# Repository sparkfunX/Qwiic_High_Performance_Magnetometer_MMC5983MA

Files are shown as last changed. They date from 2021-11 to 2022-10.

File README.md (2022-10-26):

# SparkX MMC5983MA Magnetometer Breakout

<p align="center">
  <a href="https://github.com/sparkfunX/Qwiic_High_Performance_Magnetometer_MMC5983MA/issues" alt="Issues">
    </a>
  <a href="https://github.com/sparkfunX/Qwiic_High_Performance_Magnetometer_MMC5983MA/blob/main/LICENSE.md" alt="License">
    </a>
  <a href="https://twitter.com/intent/follow?screen_name=sparkfun">
    </a>
</p>

SparkX Triple Axis Magnetometer - MMC5983MA (Qwiic) (https://www.sparkfun.com/products/19034)

*[SparkX Triple Axis Magnetometer - MMC5983MA (Qwiic) (SPX-19034)](https://www.sparkfun.com/products/19034)*

The MMC5983MA is a highly sensitive triple axis magnetometer by MEMSIC.
It is capable of sensing down to 0.4mG enabling a heading accuracy of ±0.5°.
Output rates of 1000Hz, ±8G FSR, and 18-bit resolution make the MMC5983MA a phenomenal magnetic sensor for electronic compass applications.

### Important Note:

An updated version of this product is available:

SparkFun 9DoF IMU Breakout - ISM330DHCX, MMC5983MA (Qwiic) (https://www.sparkfun.com/products/19895)

*[SparkFun 9DoF IMU Breakout - ISM330DHCX, MMC5983MA (Qwiic) (SEN-19895)](https://www.sparkfun.com/products/19895)*

SparkFun Micro Magnetometer - MMC5983MA (Qwiic) (https://www.sparkfun.com/products/19921)

*[SparkFun Micro Magnetometer - MMC5983MA (Qwiic) (SEN-19921)](https://www.sparkfun.com/products/19921)*

## Repository Contents

* **[/Documents](/Documents/)** - MMC5983MA datasheet
* **[/Hardware](/Hardware/)** - Eagle design files (.brd, .sch)

## Product Versions

* [SPX-19034](https://www.sparkfun.com/products/19034) - Initial SparkX Release

## License Information

This product is _**open source**_! 

Please review the LICENSE.md file for license information. 

If you have any questions or concerns on licensing, please contact technical support on our [SparkFun forums](https://forum.sparkfun.com/viewforum.php?f=152).

Distributed as-is; no warranty is given.

- Your friends at SparkFun.

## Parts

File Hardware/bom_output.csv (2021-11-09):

Qty | PROD_ID | Names | Value | Package
1 | CAP-00810 | C1 | 0.1uF | 0603
1 | CAP-11015 | C2 | 10uF | 0603
1 | DIO-00819 | D1 | RED | LED-0603
2 | CONN-13694 | J1; J2 | Qwiic | JST04_1MM_RA
2 | RES-08272 | R1; R2 | 2.2k | 0603
1 | RES-07856 | R3 | 1k | 0603
1 | RES-00824 | R4 | 10k | 0603
1 | IC-16314 | U1 | MMC5893MA_QFN16 | LGA-16-3X3MM-4X4PINS

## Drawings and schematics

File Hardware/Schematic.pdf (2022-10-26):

3.3V

3.3V

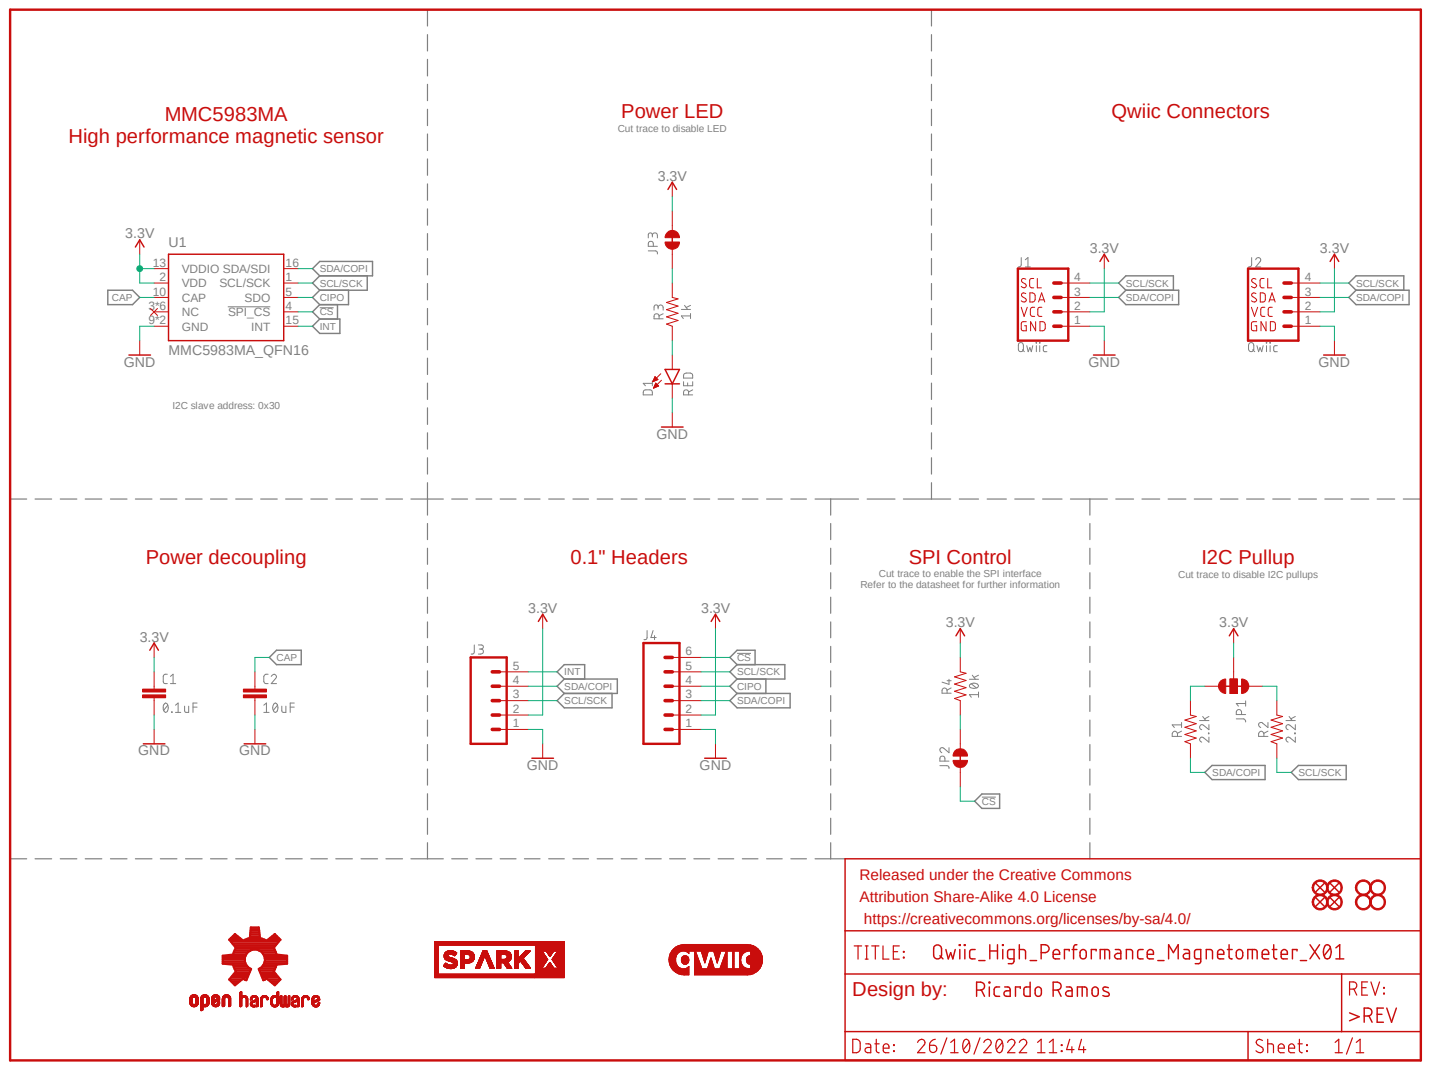
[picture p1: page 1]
I2C slave address: 0x30; Cut trace to enable the SPI interface; Cut trace to disable I2C pullups Refer to the datasheet for further information; GND; MMC5983MA_QFN16; GND 9*2; VDD 2; SCL/SCK; 1 SDA/SDI; 16 VDDIO 13; SDO; 5 CAP 10; SPI_CS; INT; 6 CAP; CAP; SDA/COPI; SDA/COPI SDA/COPI; CIPO; Qwiic Connectors; 0.1" Headers; Power LED; Power decoupling; MMC5983MA; SPI Control; I2C Pullup; Design by:

Cut trace to disable LED

High performance magnetic sensor

Released under the Creative Commons
Attribution Share-Alike 4.0 License
https://creativecommons.org/licenses/by-sa/4.0/

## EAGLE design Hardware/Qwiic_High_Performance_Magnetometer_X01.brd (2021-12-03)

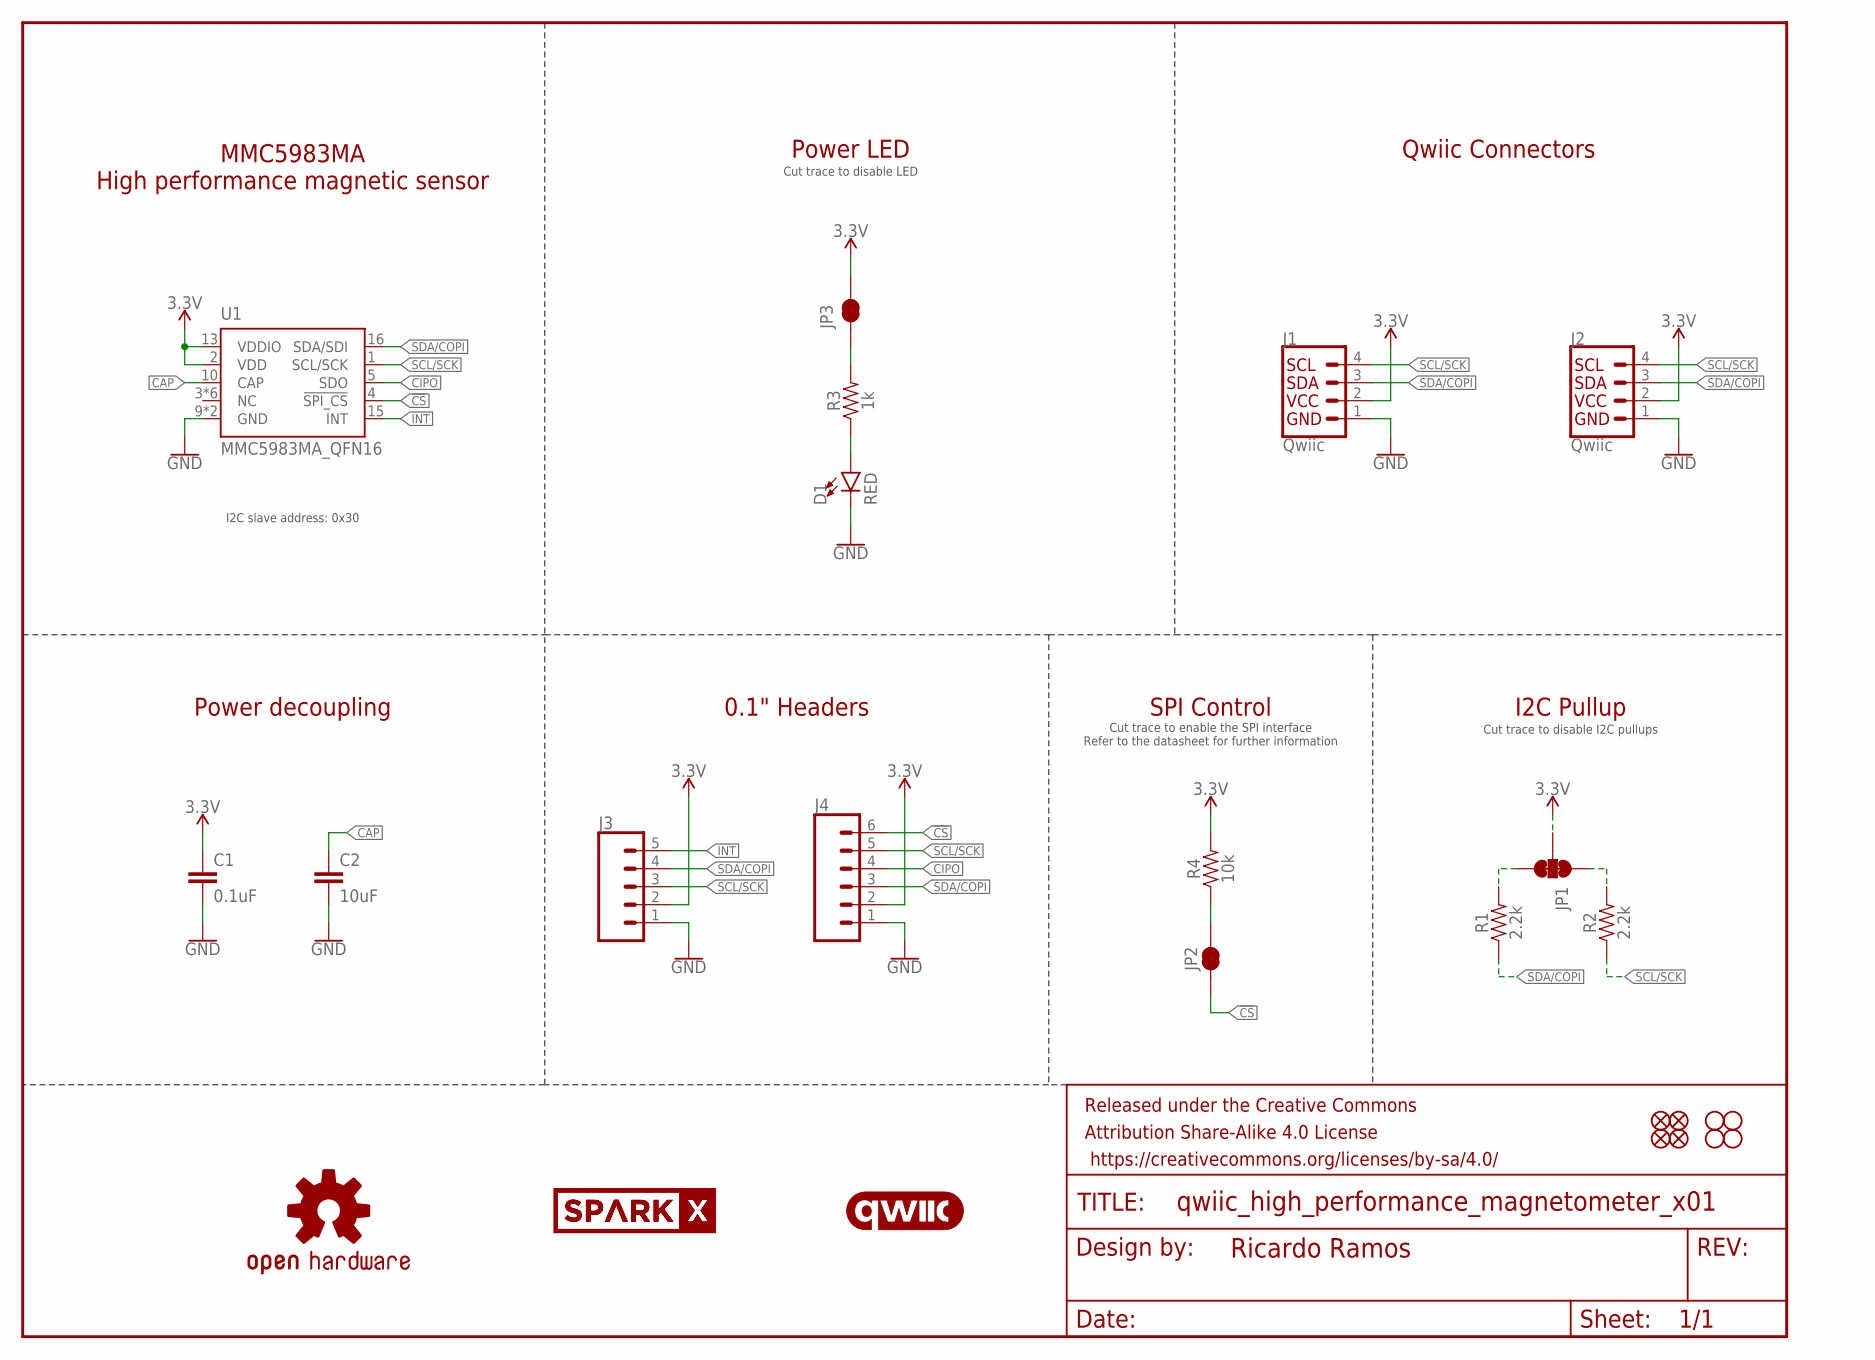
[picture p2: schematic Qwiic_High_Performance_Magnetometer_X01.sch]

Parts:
C1: 0.1uF; 0603
C2: 10uF; 0603
D1: RED; LED-0603
FD1, FD2, FD3, FD4: FIDUCIAL1X2; FIDUCIAL-1X2
FRAME1: FRAME-LETTERNO_PACKAGE; DUMMY
H1, H2, H3, H4: STAND-OFF
J1, J2: Qwiic; JST04_1MM_RA
J3: CONN_05NO_SILK; 1X05_NO_SILK
J4: CONN_06NO_SILK_NO_POP; 1X06_NO_SILK
JP1: JUMPER-SMT_3_2-NC_TRACE_SILK; SMT-JUMPER_3_2-NC_TRACE_SILK
JP2, JP3: JUMPER-SMT_2_NC_TRACE_SILK; SMT-JUMPER_2_NC_TRACE_SILK
LOGO1: OSHW-LOGOMINI; OSHW-LOGO-MINI
LOGO2: QWIIC_LOGO_5MM; QWIIC_5MM
R1, R2: 2.2k; 0603
R3: 1k; 0603
R4: 10k; 0603
U1: MMC5983MA_QFN16; LGA-16-3X3MM-4X4PINS
U$36: SPARKX-LOGO2; SPARKX-TINY
U$37: SPARKX-LOGO3; SPARKX-SMALL

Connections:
3.3V: C1.1, J1.2, J2.2, J3.2, J4.2, JP1.2, JP3.2, R4.2, U1.2 (VDD), U1.13 (VDDIO)
!CS!: J4.6, JP2.1, U1.4 (!SPI_CS!)
CAP: C2.1, U1.10 (CAP)
CIPO: J4.4, U1.5 (SDO)
GND: C1.2, C2.2, D1.C, J1.1, J2.1, J3.1, J4.1, U1.9 (GND), U1.11 (GND)
INT: J3.5, U1.15 (INT)
unnamed: JP3.1, R3.2
unnamed: JP1.1, R2.2
unnamed: JP1.3, R1.2
unnamed: D1.A, R3.1
unnamed: JP2.2, R4.1
SCL/SCK: J1.4, J2.4, J3.3, J4.5, R2.1, U1.1 (SCL/SCK)
SDA/COPI: J1.3, J2.3, J3.4, J4.3, R1.1, U1.16 (SDA/SDI)

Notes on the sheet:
Qwiic Connectors
Cut trace to disable LED
0.1" Headers
Power LED
Power decoupling
MMC5983MA High performance magnetic sensor
I2C slave address: 0x30
I2C Pullup
Cut trace to disable I2C pullups
SPI Control
Cut trace to enable the SPI interface Refer to the datasheet for further information

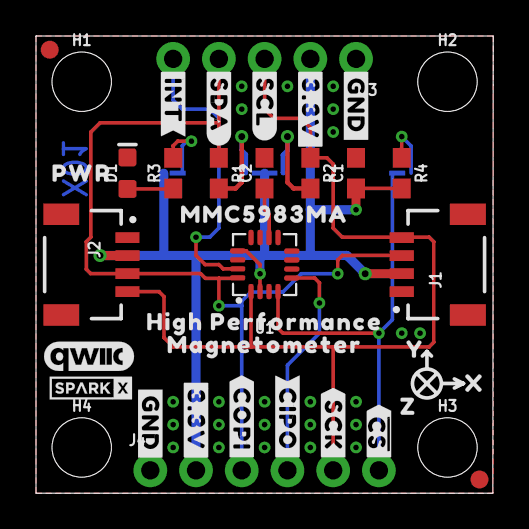
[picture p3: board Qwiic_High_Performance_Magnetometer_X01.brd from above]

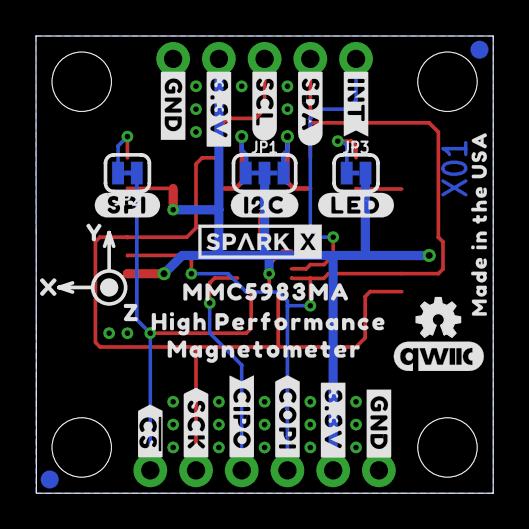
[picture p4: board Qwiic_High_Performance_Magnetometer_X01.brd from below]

Board: 2 copper layers, 25.4 x 25.4 mm, 68 parts (29 on the bottom side), 13 nets.

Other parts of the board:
LOGO3: QWIIC_LOGO_5MM; QWIIC_5MM
U$1, U$10: HIGH_PERFORMANCE11
U$2, U$35: #SCL#6
U$3, U$12, U$18, U$29: #3#3V#0
U$4, U$13, U$17, U$28: #GND#4
U$5, U$38: #SDA#5
U$6, U$31: #CIPO#11
U$7, U$16: #INT#7
U$8: PWR9
U$9, U$30: #COPI#12
U$11, U$24: MAGNETOMETER12
U$14, U$32: #SCK#13
U$15, U$33: ##CS##10
U$19, U$26: Y16
U$20, U$25: X15
U$21: #LED#8
U$22: #I2C#9
U$23: #SPI#9
U$27, U$39: Z17
U$34: MADE_IN_THE_USA20
U$41, U$42: MMC5983MA0

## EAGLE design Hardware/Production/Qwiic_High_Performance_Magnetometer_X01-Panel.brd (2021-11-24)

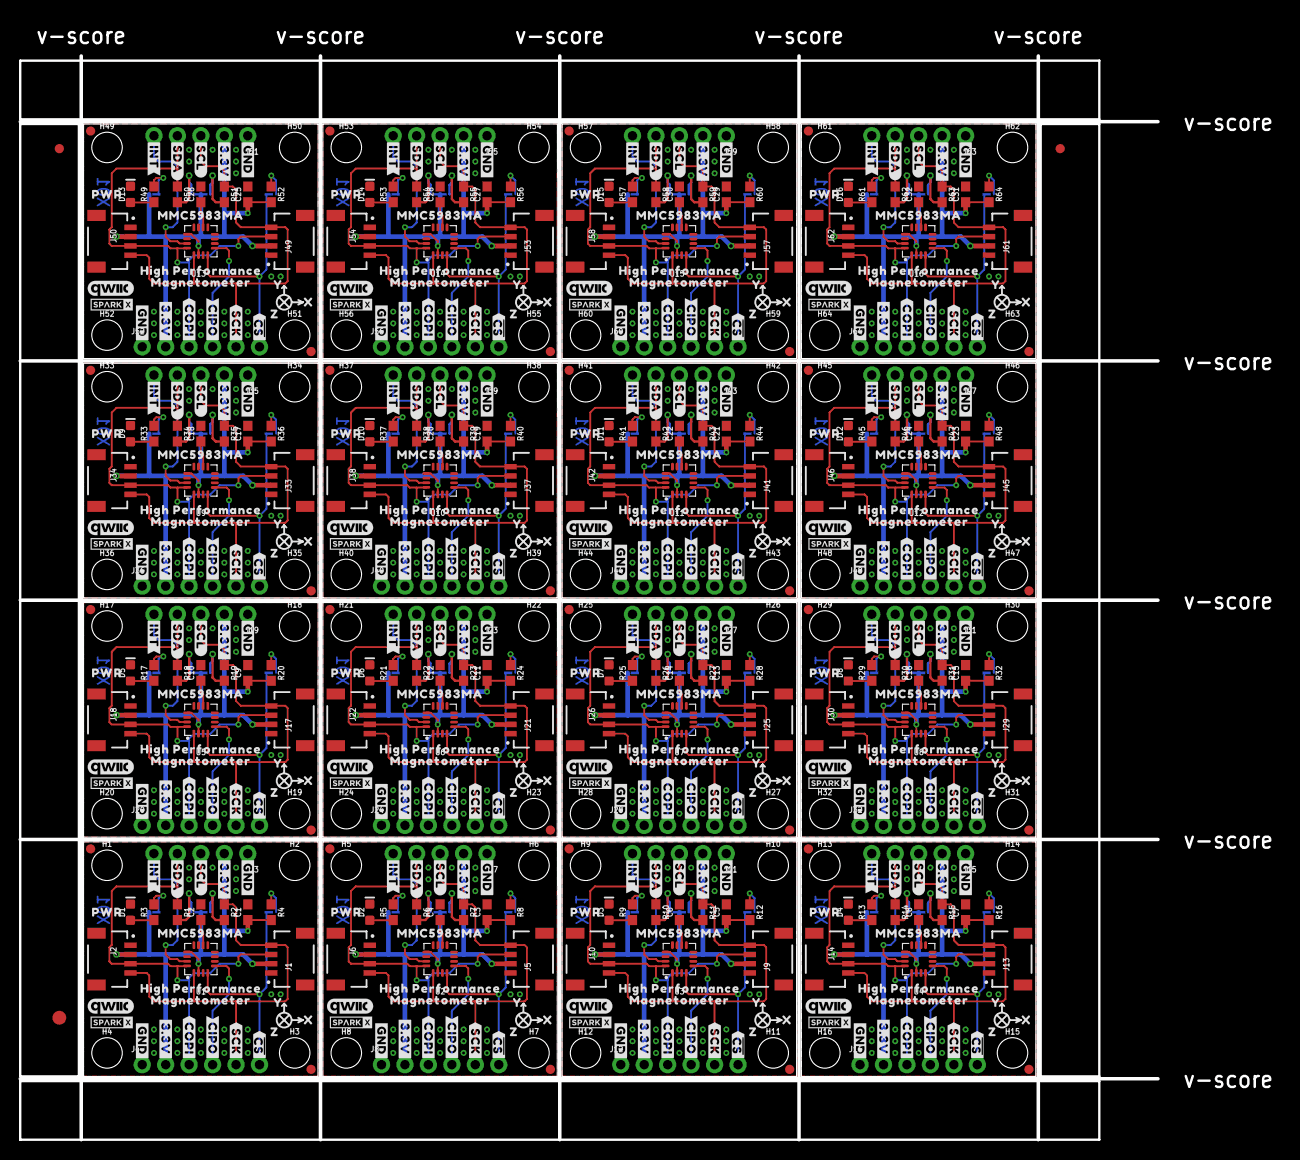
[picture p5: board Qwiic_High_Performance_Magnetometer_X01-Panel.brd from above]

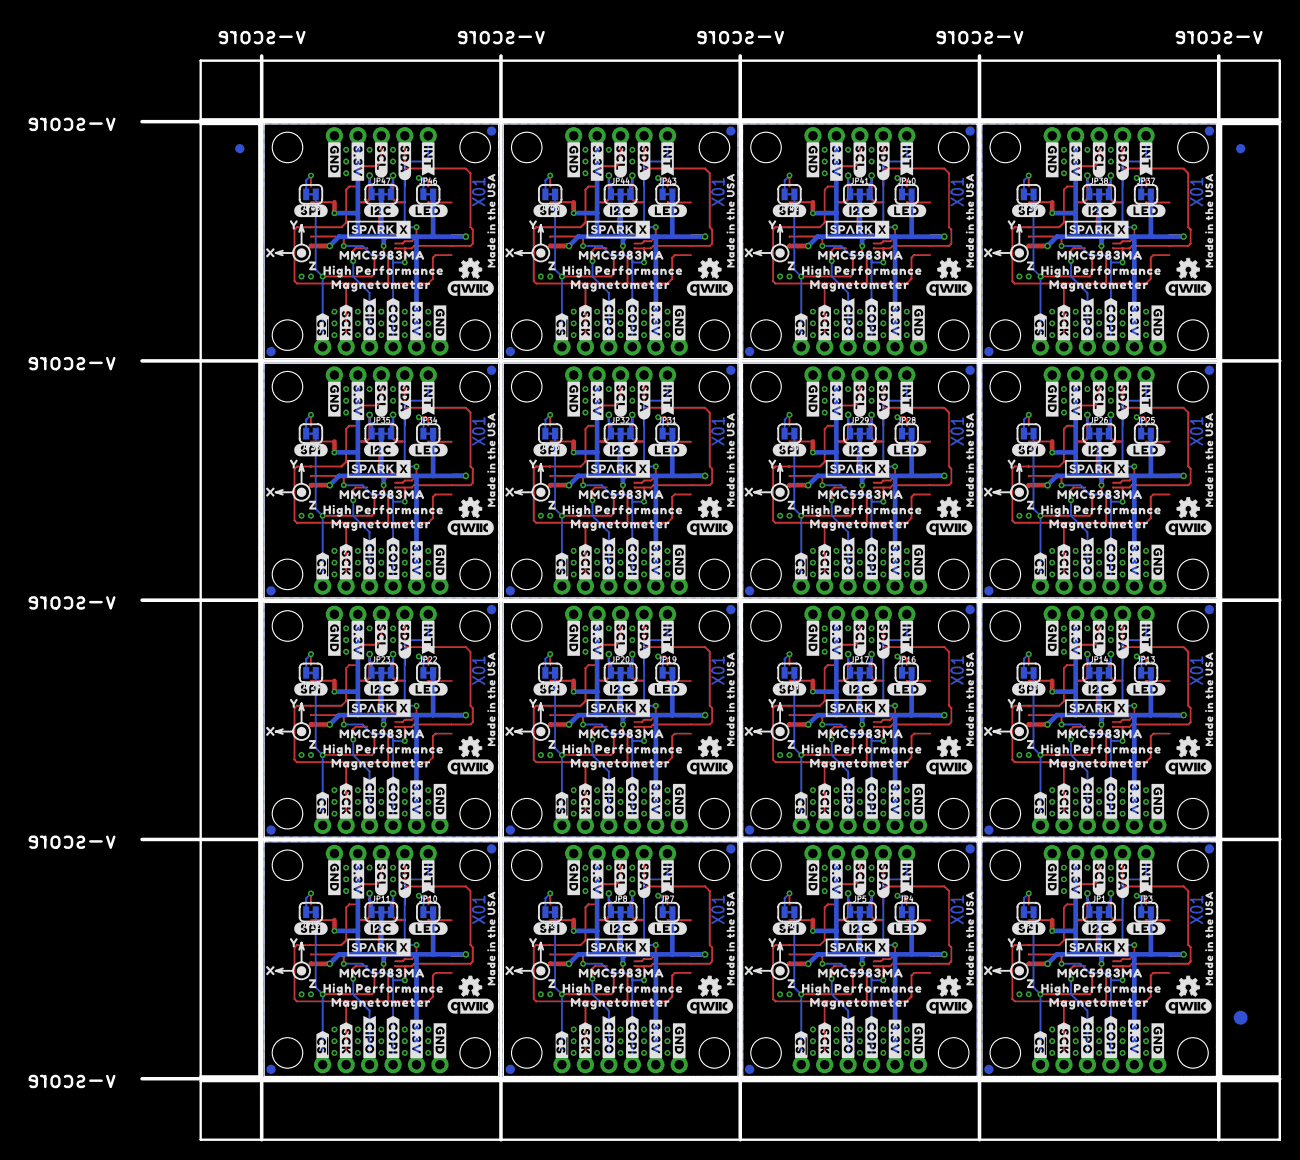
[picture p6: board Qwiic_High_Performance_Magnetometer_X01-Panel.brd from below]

Board: 2 copper layers, 123.2 x 117.3 mm, 1094 parts (467 on the bottom side), 208 nets.

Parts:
C1, C3, C5, C7, C9, C11, C13, C15, C17, C19, C21, C23, C25, C27, C29, C31: 0.1uF; 0603
C2, C4, C6, C8, C10, C12, C14, C16, C18, C20, C22, C24, C26, C28, C30, C32: 10uF; 0603
D1, D2, D3, D4, D5, D6, D7, D8, D9, D10, D11, D12, D13, D14, D15, D16: RED; LED-0603
E$1, E$2, E$3, E$4: FIDUCIAL-1X2
E$5, E$6: FIDUCIAL-1.5X3
FD1, FD2, FD3, FD4, FD5, FD6, FD7, FD8, FD9, FD10, FD11, FD12, FD13, FD14, FD15, FD16, FD17, FD18, FD19, FD20, FD21, FD22, FD23, FD24, FD25, FD26, FD27, FD28, FD29, FD30, FD31, FD32, FD33, FD34, FD35, FD36, FD37, FD38, FD39, FD40, FD41, FD42, FD43, FD44, FD45, FD46, FD47, FD48, FD49, FD50, FD51, FD52, FD53, FD54, FD55, FD56, FD57, FD58, FD59, FD60, FD61, FD62, FD63, FD64: FIDUCIAL1X2; FIDUCIAL-1X2
FRAME1, FRAME2, FRAME3, FRAME4, FRAME5, FRAME6, FRAME7, FRAME8, FRAME9, FRAME10, FRAME11, FRAME12, FRAME13, FRAME14, FRAME15, FRAME16: FRAME-LETTERNO_PACKAGE; DUMMY
H1, H2, H3, H4, H5, H6, H7, H8, H9, H10, H11, H12, H13, H14, H15, H16, H17, H18, H19, H20, H21, H22, H23, H24, H25, H26, H27, H28, H29, H30, H31, H32, H33, H34, H35, H36, H37, H38, H39, H40, H41, H42, H43, H44, H45, H46, H47, H48, H49, H50, H51, H52, H53, H54, H55, H56, H57, H58, H59, H60, H61, H62, H63, H64: STAND-OFF
J1, J2, J5, J6, J9, J10, J13, J14, J17, J18, J21, J22, J25, J26, J29, J30, J33, J34, J37, J38, J41, J42, J45, J46, J49, J50, J53, J54, J57, J58, J61, J62: Qwiic; JST04_1MM_RA
J3, J7, J11, J15, J19, J23, J27, J31, J35, J39, J43, J47, J51, J55, J59, J63: 1X05_NO_SILK
J4, J8, J12, J16, J20, J24, J28, J32, J36, J40, J44, J48, J52, J56, J60, J64: 1X06_NO_SILK
JP1, JP5, JP8, JP11, JP14, JP17, JP20, JP23, JP26, JP29, JP32, JP35, JP38, JP41, JP44, JP47: JUMPER-SMT_3_2-NC_TRACE_SILK; SMT-JUMPER_3_2-NC_TRACE_SILK
JP2, JP3, JP4, JP6, JP7, JP9, JP10, JP12, JP13, JP15, JP16, JP18, JP19, JP21, JP22, JP24, JP25, JP27, JP28, JP30, JP31, JP33, JP34, JP36, JP37, JP39, JP40, JP42, JP43, JP45, JP46, JP48: JUMPER-SMT_2_NC_TRACE_SILK; SMT-JUMPER_2_NC_TRACE_SILK
LOGO1, LOGO4, LOGO7, LOGO10, LOGO13, LOGO16, LOGO19, LOGO22, LOGO25, LOGO28, LOGO31, LOGO34, LOGO37, LOGO40, LOGO43, LOGO46: OSHW-LOGOMINI; OSHW-LOGO-MINI
LOGO2, LOGO3, LOGO5, LOGO6, LOGO8, LOGO9, LOGO11, LOGO12, LOGO14, LOGO15, LOGO17, LOGO18, LOGO20, LOGO21, LOGO23, LOGO24, LOGO26, LOGO27, LOGO29, LOGO30, LOGO32, LOGO33, LOGO35, LOGO36, LOGO38, LOGO39, LOGO41, LOGO42, LOGO44, LOGO45, LOGO47, LOGO48: QWIIC_LOGO_5MM; QWIIC_5MM
R1, R2, R6, R7, R10, R11, R14, R15, R18, R19, R22, R23, R26, R27, R30, R31, R34, R35, R38, R39, R42, R43, R46, R47, R50, R51, R54, R55, R58, R59, R62, R63: 2.2k; 0603
R3, R5, R9, R13, R17, R21, R25, R29, R33, R37, R41, R45, R49, R53, R57, R61: 1k; 0603
R4, R8, R12, R16, R20, R24, R28, R32, R36, R40, R44, R48, R52, R56, R60, R64: 10k; 0603
U1, U2, U3, U4, U5, U6, U7, U8, U9, U10, U11, U12, U13, U14, U15, U16: MMC5893MA_QFN16; LGA-16-3X3MM-4X4PINS
U$1, U$10, U$46, U$67, U$87, U$108, U$128, U$149, U$169, U$190, U$210, U$231, U$251, U$272, U$292, U$313, U$333, U$354, U$374, U$395, U$415, U$436, U$456, U$477, U$497, U$518, U$538, U$559, U$579, U$600, U$620, U$641: HIGH_PERFORMANCE11
U$2, U$35, U$54, U$78, U$95, U$119, U$136, U$160, U$177, U$201, U$218, U$242, U$259, U$283, U$300, U$324, U$341, U$365, U$382, U$406, U$423, U$447, U$464, U$488, U$505, U$529, U$546, U$570, U$587, U$611, U$628, U$652: #SCL#6
U$3, U$12, U$18, U$29, U$40, U$48, U$60, U$70, U$83, U$89, U$101, U$111, U$124, U$130, U$142, U$152, U$165, U$171, U$183, U$193, U$206, U$212, U$224, U$234, U$247, U$253, U$265, U$275, U$288, U$294, U$306, U$316, U$329, U$335, U$347, U$357, U$370, U$376, U$388, U$398, U$411, U$417, U$429, U$439, U$452, U$458, U$470, U$480, U$493, U$499, U$511, U$521, U$534, U$540, U$552, U$562, U$575, U$581, U$593, U$603, U$616, U$622, U$634, U$644: #3#3V#0
U$4, U$13, U$17, U$28, U$43, U$49, U$66, U$69, U$84, U$90, U$107, U$110, U$125, U$131, U$148, U$151, U$166, U$172, U$189, U$192, U$207, U$213, U$230, U$233, U$248, U$254, U$271, U$274, U$289, U$295, U$312, U$315, U$330, U$336, U$353, U$356, U$371, U$377, U$394, U$397, U$412, U$418, U$435, U$438, U$453, U$459, U$476, U$479, U$494, U$500, U$517, U$520, U$535, U$541, U$558, U$561, U$576, U$582, U$599, U$602, U$617, U$623, U$640, U$643: #GND#4
U$5, U$38, U$55, U$79, U$96, U$120, U$137, U$161, U$178, U$202, U$219, U$243, U$260, U$284, U$301, U$325, U$342, U$366, U$383, U$407, U$424, U$448, U$465, U$489, U$506, U$530, U$547, U$571, U$588, U$612, U$629, U$653: #SDA#5
U$6, U$31, U$56, U$72, U$97, U$113, U$138, U$154, U$179, U$195, U$220, U$236, U$261, U$277, U$302, U$318, U$343, U$359, U$384, U$400, U$425, U$441, U$466, U$482, U$507, U$523, U$548, U$564, U$589, U$605, U$630, U$646: #CIPO#11
U$7, U$16, U$44, U$50, U$85, U$91, U$126, U$132, U$167, U$173, U$208, U$214, U$249, U$255, U$290, U$296, U$331, U$337, U$372, U$378, U$413, U$419, U$454, U$460, U$495, U$501, U$536, U$542, U$577, U$583, U$618, U$624: #INT#7
U$8, U$45, U$86, U$127, U$168, U$209, U$250, U$291, U$332, U$373, U$414, U$455, U$496, U$537, U$578, U$619: PWR9
U$9, U$30, U$57, U$71, U$98, U$112, U$139, U$153, U$180, U$194, U$221, U$235, U$262, U$276, U$303, U$317, U$344, U$358, U$385, U$399, U$426, U$440, U$467, U$481, U$508, U$522, U$549, U$563, U$590, U$604, U$631, U$645: #COPI#12
U$11, U$24, U$47, U$68, U$88, U$109, U$129, U$150, U$170, U$191, U$211, U$232, U$252, U$273, U$293, U$314, U$334, U$355, U$375, U$396, U$416, U$437, U$457, U$478, U$498, U$519, U$539, U$560, U$580, U$601, U$621, U$642: MAGNETOMETER12
U$14, U$32, U$58, U$73, U$99, U$114, U$140, U$155, U$181, U$196, U$222, U$237, U$263, U$278, U$304, U$319, U$345, U$360, U$386, U$401, U$427, U$442, U$468, U$483, U$509, U$524, U$550, U$565, U$591, U$606, U$632, U$647: #SCK#13
U$15, U$33, U$59, U$74, U$100, U$115, U$141, U$156, U$182, U$197, U$223, U$238, U$264, U$279, U$305, U$320, U$346, U$361, U$387, U$402, U$428, U$443, U$469, U$484, U$510, U$525, U$551, U$566, U$592, U$607, U$633, U$648: ##CS##10
U$19, U$26, U$61, U$64, U$102, U$105, U$143, U$146, U$184, U$187, U$225, U$228, U$266, U$269, U$307, U$310, U$348, U$351, U$389, U$392, U$430, U$433, U$471, U$474, U$512, U$515, U$553, U$556, U$594, U$597, U$635, U$638: Y16
U$20, U$25, U$62, U$63, U$103, U$104, U$144, U$145, U$185, U$186, U$226, U$227, U$267, U$268, U$308, U$309, U$349, U$350, U$390, U$391, U$431, U$432, U$472, U$473, U$513, U$514, U$554, U$555, U$595, U$596, U$636, U$637: X15
U$21, U$51, U$92, U$133, U$174, U$215, U$256, U$297, U$338, U$379, U$420, U$461, U$502, U$543, U$584, U$625: #LED#8
U$22, U$52, U$93, U$134, U$175, U$216, U$257, U$298, U$339, U$380, U$421, U$462, U$503, U$544, U$585, U$626: #I2C#9
U$23, U$53, U$94, U$135, U$176, U$217, U$258, U$299, U$340, U$381, U$422, U$463, U$504, U$545, U$586, U$627: #SPI#9
U$27, U$39, U$65, U$80, U$106, U$121, U$147, U$162, U$188, U$203, U$229, U$244, U$270, U$285, U$311, U$326, U$352, U$367, U$393, U$408, U$434, U$449, U$475, U$490, U$516, U$531, U$557, U$572, U$598, U$613, U$639, U$654: Z17
U$34, U$77, U$118, U$159, U$200, U$241, U$282, U$323, U$364, U$405, U$446, U$487, U$528, U$569, U$610, U$651: MADE_IN_THE_USA20
U$36, U$75, U$116, U$157, U$198, U$239, U$280, U$321, U$362, U$403, U$444, U$485, U$526, U$567, U$608, U$649: SPARKX-LOGO2; SPARKX-TINY
U$37, U$76, U$117, U$158, U$199, U$240, U$281, U$322, U$363, U$404, U$445, U$486, U$527, U$568, U$609, U$650: SPARKX-LOGO3; SPARKX-SMALL
U$41, U$42, U$81, U$82, U$122, U$123, U$163, U$164, U$204, U$205, U$245, U$246, U$286, U$287, U$327, U$328, U$368, U$369, U$409, U$410, U$450, U$451, U$491, U$492, U$532, U$533, U$573, U$574, U$614, U$615, U$655, U$656: MMC5983MA0

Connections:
3.3V: C1.1, J1.2, J2.2, J3.2, J4.2, JP1.2, JP3.2, R4.2, U1.2, U1.13
3.3V1: C3.1, J5.2, J6.2, J7.2, J8.2, JP4.2, JP5.2, R8.2, U2.2, U2.13
3.3V2: C5.1, J9.2, J10.2, J11.2, J12.2, JP7.2, JP8.2, R12.2, U3.2, U3.13
3.3V3: C7.1, J13.2, J14.2, J15.2, J16.2, JP10.2, JP11.2, R16.2, U4.2, U4.13
3.3V4: C9.1, J17.2, J18.2, J19.2, J20.2, JP13.2, JP14.2, R20.2, U5.2, U5.13
3.3V5: C11.1, J21.2, J22.2, J23.2, J24.2, JP16.2, JP17.2, R24.2, U6.2, U6.13
3.3V6: C13.1, J25.2, J26.2, J27.2, J28.2, JP19.2, JP20.2, R28.2, U7.2, U7.13
3.3V7: C15.1, J29.2, J30.2, J31.2, J32.2, JP22.2, JP23.2, R32.2, U8.2, U8.13
3.3V8: C17.1, J33.2, J34.2, J35.2, J36.2, JP25.2, JP26.2, R36.2, U9.2, U9.13
3.3V9: C19.1, J37.2, J38.2, J39.2, J40.2, JP28.2, JP29.2, R40.2, U10.2, U10.13
3.3V10: C21.1, J41.2, J42.2, J43.2, J44.2, JP31.2, JP32.2, R44.2, U11.2, U11.13
3.3V11: C23.1, J45.2, J46.2, J47.2, J48.2, JP34.2, JP35.2, R48.2, U12.2, U12.13
3.3V12: C25.1, J49.2, J50.2, J51.2, J52.2, JP37.2, JP38.2, R52.2, U13.2, U13.13
3.3V13: C27.1, J53.2, J54.2, J55.2, J56.2, JP40.2, JP41.2, R56.2, U14.2, U14.13
3.3V14: C29.1, J57.2, J58.2, J59.2, J60.2, JP43.2, JP44.2, R60.2, U15.2, U15.13
3.3V15: C31.1, J61.2, J62.2, J63.2, J64.2, JP46.2, JP47.2, R64.2, U16.2, U16.13
!CS!: J4.6, JP2.1, U1.4
!CS!1: J8.6, JP6.1, U2.4
!CS!2: J12.6, JP9.1, U3.4
!CS!3: J16.6, JP12.1, U4.4
!CS!4: J20.6, JP15.1, U5.4
!CS!5: J24.6, JP18.1, U6.4
!CS!6: J28.6, JP21.1, U7.4
!CS!7: J32.6, JP24.1, U8.4
!CS!8: J36.6, JP27.1, U9.4
!CS!9: J40.6, JP30.1, U10.4
!CS!10: J44.6, JP33.1, U11.4
!CS!11: J48.6, JP36.1, U12.4
!CS!12: J52.6, JP39.1, U13.4
!CS!13: J56.6, JP42.1, U14.4
!CS!14: J60.6, JP45.1, U15.4
!CS!15: J64.6, JP48.1, U16.4
CAP: C2.1, U1.10
CAP1: C4.1, U2.10
CAP2: C6.1, U3.10
CAP3: C8.1, U4.10
CAP4: C10.1, U5.10
CAP5: C12.1, U6.10
CAP6: C14.1, U7.10
CAP7: C16.1, U8.10
CAP8: C18.1, U9.10
CAP9: C20.1, U10.10
CAP10: C22.1, U11.10
CAP11: C24.1, U12.10
CAP12: C26.1, U13.10
CAP13: C28.1, U14.10
CAP14: C30.1, U15.10
CAP15: C32.1, U16.10
CIPO: J4.4, U1.5
CIPO1: J8.4, U2.5
CIPO2: J12.4, U3.5
CIPO3: J16.4, U4.5
CIPO4: J20.4, U5.5
CIPO5: J24.4, U6.5
CIPO6: J28.4, U7.5
CIPO7: J32.4, U8.5
CIPO8: J36.4, U9.5
CIPO9: J40.4, U10.5
CIPO10: J44.4, U11.5
CIPO11: J48.4, U12.5
CIPO12: J52.4, U13.5
CIPO13: J56.4, U14.5
CIPO14: J60.4, U15.5
CIPO15: J64.4, U16.5
GND: C1.2, C2.2, D1.C, J1.1, J2.1, J3.1, J4.1, U1.9, U1.11
GND1: C3.2, C4.2, D2.C, J5.1, J6.1, J7.1, J8.1, U2.9, U2.11
GND2: C5.2, C6.2, D3.C, J9.1, J10.1, J11.1, J12.1, U3.9, U3.11
GND3: C7.2, C8.2, D4.C, J13.1, J14.1, J15.1, J16.1, U4.9, U4.11
GND4: C9.2, C10.2, D5.C, J17.1, J18.1, J19.1, J20.1, U5.9, U5.11
GND5: C11.2, C12.2, D6.C, J21.1, J22.1, J23.1, J24.1, U6.9, U6.11
GND6: C13.2, C14.2, D7.C, J25.1, J26.1, J27.1, J28.1, U7.9, U7.11
GND7: C15.2, C16.2, D8.C, J29.1, J30.1, J31.1, J32.1, U8.9, U8.11
GND8: C17.2, C18.2, D9.C, J33.1, J34.1, J35.1, J36.1, U9.9, U9.11
GND9: C19.2, C20.2, D10.C, J37.1, J38.1, J39.1, J40.1, U10.9, U10.11
GND10: C21.2, C22.2, D11.C, J41.1, J42.1, J43.1, J44.1, U11.9, U11.11
GND11: C23.2, C24.2, D12.C, J45.1, J46.1, J47.1, J48.1, U12.9, U12.11
GND12: C25.2, C26.2, D13.C, J49.1, J50.1, J51.1, J52.1, U13.9, U13.11
GND13: C27.2, C28.2, D14.C, J53.1, J54.1, J55.1, J56.1, U14.9, U14.11
GND14: C29.2, C30.2, D15.C, J57.1, J58.1, J59.1, J60.1, U15.9, U15.11
GND15: C31.2, C32.2, D16.C, J61.1, J62.1, J63.1, J64.1, U16.9, U16.11
INT: J3.5, U1.15
INT1: J7.5, U2.15
INT2: J11.5, U3.15
INT3: J15.5, U4.15
INT4: J19.5, U5.15
INT5: J23.5, U6.15
INT6: J27.5, U7.15
INT7: J31.5, U8.15
INT8: J35.5, U9.15
INT9: J39.5, U10.15
INT10: J43.5, U11.15
INT11: J47.5, U12.15
INT12: J51.5, U13.15
INT13: J55.5, U14.15
INT14: J59.5, U15.15
INT15: J63.5, U16.15
unnamed: JP3.1, R3.2
unnamed: JP1.1, R2.2
unnamed: JP1.3, R1.2
unnamed: D1.A, R3.1
unnamed: JP2.2, R4.1
unnamed: JP4.1, R5.2
unnamed: D2.A, R5.1
unnamed: JP5.1, R7.2
unnamed: JP5.3, R6.2
unnamed: JP6.2, R8.1
unnamed: JP7.1, R9.2
unnamed: D3.A, R9.1
unnamed: JP8.1, R11.2
unnamed: JP8.3, R10.2
unnamed: JP9.2, R12.1
unnamed: JP10.1, R13.2
unnamed: D4.A, R13.1
unnamed: JP11.1, R15.2
unnamed: JP11.3, R14.2
unnamed: JP12.2, R16.1
unnamed: JP13.1, R17.2
unnamed: D5.A, R17.1
unnamed: JP14.1, R19.2
unnamed: JP14.3, R18.2
unnamed: JP15.2, R20.1
unnamed: JP16.1, R21.2
unnamed: D6.A, R21.1
unnamed: JP17.1, R23.2
unnamed: JP17.3, R22.2
unnamed: JP18.2, R24.1
unnamed: JP19.1, R25.2
unnamed: D7.A, R25.1
unnamed: JP20.1, R27.2
unnamed: JP20.3, R26.2
unnamed: JP21.2, R28.1
unnamed: JP22.1, R29.2
unnamed: D8.A, R29.1
unnamed: JP23.1, R31.2
unnamed: JP23.3, R30.2
unnamed: JP24.2, R32.1
unnamed: JP25.1, R33.2
unnamed: D9.A, R33.1
unnamed: JP26.1, R35.2
unnamed: JP26.3, R34.2
unnamed: JP27.2, R36.1
unnamed: JP28.1, R37.2
unnamed: D10.A, R37.1
unnamed: JP29.1, R39.2
unnamed: JP29.3, R38.2
unnamed: JP30.2, R40.1
unnamed: JP31.1, R41.2
unnamed: D11.A, R41.1
unnamed: JP32.1, R43.2
unnamed: JP32.3, R42.2
unnamed: JP33.2, R44.1
unnamed: JP34.1, R45.2
unnamed: D12.A, R45.1
unnamed: JP35.1, R47.2
unnamed: JP35.3, R46.2
unnamed: JP36.2, R48.1
unnamed: JP37.1, R49.2
unnamed: D13.A, R49.1
unnamed: JP38.1, R51.2
unnamed: JP38.3, R50.2
unnamed: JP39.2, R52.1
unnamed: JP40.1, R53.2
unnamed: D14.A, R53.1
unnamed: JP41.1, R55.2
unnamed: JP41.3, R54.2
unnamed: JP42.2, R56.1
unnamed: JP43.1, R57.2
unnamed: D15.A, R57.1
unnamed: JP44.1, R59.2
unnamed: JP44.3, R58.2
unnamed: JP45.2, R60.1
unnamed: JP46.1, R61.2
unnamed: D16.A, R61.1
unnamed: JP47.1, R63.2
unnamed: JP47.3, R62.2
unnamed: JP48.2, R64.1
SCL/SCK: J1.4, J2.4, J3.3, J4.5, R2.1, U1.1
SCL/SCK1: J5.4, J6.4, J7.3, J8.5, R7.1, U2.1
SCL/SCK2: J9.4, J10.4, J11.3, J12.5, R11.1, U3.1
SCL/SCK3: J13.4, J14.4, J15.3, J16.5, R15.1, U4.1
SCL/SCK4: J17.4, J18.4, J19.3, J20.5, R19.1, U5.1
SCL/SCK5: J21.4, J22.4, J23.3, J24.5, R23.1, U6.1
SCL/SCK6: J25.4, J26.4, J27.3, J28.5, R27.1, U7.1
SCL/SCK7: J29.4, J30.4, J31.3, J32.5, R31.1, U8.1
SCL/SCK8: J33.4, J34.4, J35.3, J36.5, R35.1, U9.1
SCL/SCK9: J37.4, J38.4, J39.3, J40.5, R39.1, U10.1
SCL/SCK10: J41.4, J42.4, J43.3, J44.5, R43.1, U11.1
SCL/SCK11: J45.4, J46.4, J47.3, J48.5, R47.1, U12.1
SCL/SCK12: J49.4, J50.4, J51.3, J52.5, R51.1, U13.1
SCL/SCK13: J53.4, J54.4, J55.3, J56.5, R55.1, U14.1
SCL/SCK14: J57.4, J58.4, J59.3, J60.5, R59.1, U15.1
SCL/SCK15: J61.4, J62.4, J63.3, J64.5, R63.1, U16.1
SDA/COPI: J1.3, J2.3, J3.4, J4.3, R1.1, U1.16
SDA/COPI1: J5.3, J6.3, J7.4, J8.3, R6.1, U2.16
SDA/COPI2: J9.3, J10.3, J11.4, J12.3, R10.1, U3.16
SDA/COPI3: J13.3, J14.3, J15.4, J16.3, R14.1, U4.16
SDA/COPI4: J17.3, J18.3, J19.4, J20.3, R18.1, U5.16
SDA/COPI5: J21.3, J22.3, J23.4, J24.3, R22.1, U6.16
SDA/COPI6: J25.3, J26.3, J27.4, J28.3, R26.1, U7.16
SDA/COPI7: J29.3, J30.3, J31.4, J32.3, R30.1, U8.16
SDA/COPI8: J33.3, J34.3, J35.4, J36.3, R34.1, U9.16
SDA/COPI9: J37.3, J38.3, J39.4, J40.3, R38.1, U10.16
SDA/COPI10: J41.3, J42.3, J43.4, J44.3, R42.1, U11.16
SDA/COPI11: J45.3, J46.3, J47.4, J48.3, R46.1, U12.16
SDA/COPI12: J49.3, J50.3, J51.4, J52.3, R50.1, U13.16
SDA/COPI13: J53.3, J54.3, J55.4, J56.3, R54.1, U14.16
SDA/COPI14: J57.3, J58.3, J59.4, J60.3, R58.1, U15.16
SDA/COPI15: J61.3, J62.3, J63.4, J64.3, R62.1, U16.16

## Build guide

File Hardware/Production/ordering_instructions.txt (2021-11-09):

panel size, 117x117mm
PCB thickness, 1.6mm
number of layers, 2
soldermask color, Black
silkscreen color, White
oz copper, 1oz
finish, HASL lead free
stencils, top
pcs per panel, 16
min trace width, 0.2032mm / 0.0080in
min drill size, 0.3048mm / 0.0120in

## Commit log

2021-11-04 Initial version uploaded.
    [Qwiic_High_Performance_Magnetometer.brd, Qwiic_High_Performance_Magnetometer.sch]
2021-11-04 Created production files
    [Qwiic_High_Performance_Magnetometer-Panel.GBL, Qwiic_High_Performance_Magnetometer-Panel.GBO, Qwiic_High_Performance_Magnetometer-Panel.GBP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]
2021-11-09 Added SPI breakout header; created PCB production files.
    [Qwiic_High_Performance_Magnetometer-Panel.GBL, Qwiic_High_Performance_Magnetometer-Panel.GBO, Qwiic_High_Performance_Magnetometer-Panel.GBS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]
2021-11-09 Fixed SPI header alignment.
    [Qwiic_High_Performance_Magnetometer-Panel.brd, Qwiic_High_Performance_Magnetometer.brd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]
2021-11-09 Improved top ground plane under the IC.
    [Qwiic_High_Performance_Magnetometer.brd]
2021-11-09 Renamed file to reflect version. Added PCB version to bottom silk.
    [Qwiic_High_Performance_Magnetometer-Panel.GBL, Qwiic_High_Performance_Magnetometer-Panel.GBO, Qwiic_High_Performance_Magnetometer-Panel.GBP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]
2021-11-09 Added bom csv file.
    [bom_output.csv]
2021-11-24 Added production files; updated BOM.
    [Qwiic_High_Performance_Magnetometer_X01-Panel.brd, Qwiic_High_Performance_Magnetometer_X01.brd, bom_output.csv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]
2021-12-03 Fixed typo
    [Qwiic_High_Performance_Magnetometer_X01.brd, Qwiic_High_Performance_Magnetometer_X01.sch]

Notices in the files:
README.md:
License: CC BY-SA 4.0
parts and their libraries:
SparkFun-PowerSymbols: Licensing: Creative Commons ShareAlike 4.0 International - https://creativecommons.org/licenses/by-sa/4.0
